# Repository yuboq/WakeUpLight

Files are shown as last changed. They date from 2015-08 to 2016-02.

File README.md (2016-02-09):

Currently, this device turns on LED strip at 5AM, and gradually increases in brightness in a half hour period.
Demo can be found here:
https://youtu.be/3JCAbMRWAIY

Eventually, the goal for this project is to create a beautiful standalone alarm clock that can help others wake up more naturally, similar to the Philips Wake Up Light, but with more customizations

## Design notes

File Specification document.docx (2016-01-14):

# Arduino wakeup light documentation

By Yubo Qiu

August 9, 2015

This functional specification will be available in PDF format for those who don’t have/use Word.

# Change Log

Author | Date | Notes
Yubo Qiu | Aug 9, 2015 | Initial Draft

Table of Contents

# 1. Introduction

## 1.1 Brief History of this project

This project started because my mother said that she was always waking up tired in the winter. After some research, I figured out that she was tired because the alarm clock would jolt her awake, instead of being woken up by the sunrise, like in summer. A quick search suggested that the Philips wake-up light would be a great solution to this, but costed $100 or so. I wanted a cheaper solution, so I decided to go the DIY route. I figured that since I already had some background in PCB development, this would be a great opportunity to go from initial concept to final delivery. I can also learn a bit about microcontrollers along the way!

Of course, the first thing was to look online, but I quickly found that those DIY solutions were unpolished. Of course, my solution might end up the same, but at least I’ll have control over that and decide the tradeoffs on my own terms. So, I ended up deciding to build this entire project from scratch, just to know how it feels.

## 1.2 Purpose of this document

This document is intended to describe functional specifications of the wake-up light. This document specifies the all components of this project, including PCB, firmware, mechanical and debugging. The intended audience is for anyone looking for a practical beginner project, and for developers to make sure that all design criteria are met.

## 1.3 Scope of the project

The wakeup light gradually increases the brightness of the LED strips to simulate a sunrise. This provides a more natural wake-up, rather than an alarm clock to jolt you awake. This project is also intended to be a starting point for anyone else wanting to build a wake-up light themselves—it doesn’t require advanced knowledge of circuit design or programming, instead, it requires you to follow through.

# 2. General Description

The wakeup light gradually increases the brightness of the LED strips to simulate a sunrise. Since all the code is on Github, I encourage the end user to change the code to make the light better.

## 2.1 Functions

## 2.2 Cost

The cost is at around $30 for hardware alone, however, depending on where you source components, you may get it cheaper. You do not need quality components, stuff from eBay is fine (that’s where I sourced my stuff).

# 3. Functional Requirements

## 3.1 User Interface

The rotary encoder controls the majority of the configurations, where turning the encoder scrolls through the menu items, and pushing the button selects the item. such as alarm/clock/date set, alarm on/off, and light on/off. When the alarm is set, the Arduino gradually turns up an LED strip over a specified period (default 30min). Another functions include a delayed off, where you gradually dim the light before turning off.

## 3.2 Software

Stuff happens here

### 3.2.1 State machine for rotary encoder

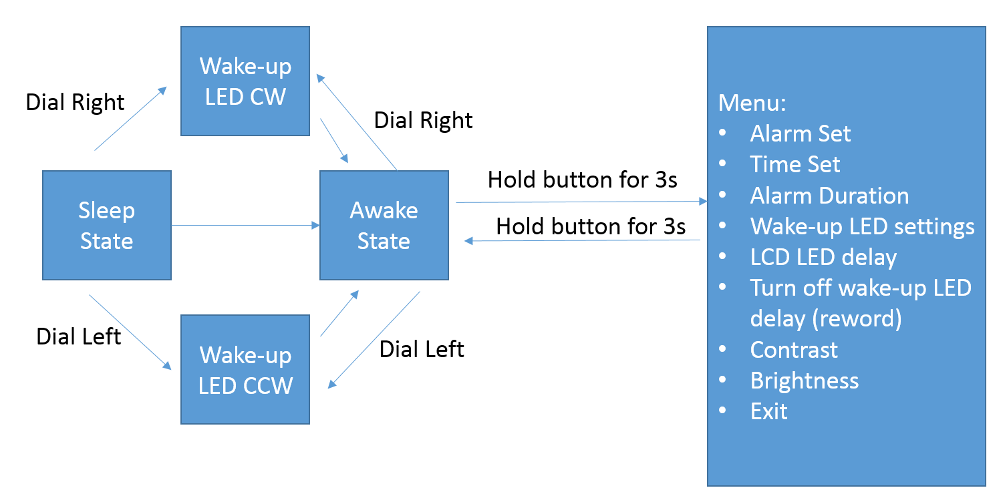
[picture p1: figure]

#### 3.2.1.1 Sleep State

By default the clock is in sleep state, where the LCD LED is off, and the clock and date is shown

#### 3.2.1.2 Awake State

When the dial is turned left/right or pressed, then the clock will enter awake state where the LCD LED will turn on.

#### 3.2.1.3 Menu state

The menu state will be displayed when the button is held for 3s. TO leave the menu state, hold the button for 3s, or navigate to exit.

### 3.2.2 Wi-Fi

Add wi-fi compatability to control from web-browser

### 3.2.3 Mobile app

Android or iOS app that connects to the device through wifi

  3.3 Block diagram

## 3.4 Hardware

- 16x2 LCD with backlight
- Custom PCB
- Arduino nano or mini
- External Clock oscillator
- Push button
- Caps and resistors
- LED light strip

# 4. Mechanical

- All components must fit in a LxWxH: 3.5” x 3.5” x 1.5” enclosure
- Rotary encoder will protrude from the middle of the enclosure

# 5. Debugging

# 6. Further development

Wi-fi integration for android/iOS

Remote control functionality

Add a python wrapper

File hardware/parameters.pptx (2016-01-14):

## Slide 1

Block Diagram

12V supply

Push Button (rotary encoder)

Arduino Mini/Nano

FETs

LED strip

External clock

Fog ligts

Serial Comm

16x2 LCD display

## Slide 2

(Rough) Layout*

PCB Specifications:
- 2” x 2”
- 2 layer board
- 1.6mm thick
- HASL finish
- 1 oz copper
- Min trace 6mil (recommend >8mil)
- Min space 6min (recommended >8mil)
- Finished hole (0.3mm – 6.3mm)

Enclosure Specifications:
- L x W x H: 3.5” x 3.5” x 1.5”
- Rotary encoder button must protrude from the middle of the enclosure

3.5”

2”

Arduino mini/nano dual footprint

LCD display

Power stuff

Serial header

FETs

External clock

LED header

2”

Btn

3.5”

*Not to scale

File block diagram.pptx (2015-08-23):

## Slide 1

Wake-up LED CW

Menu:
- Alarm Set
- Time Set
- Alarm Duration
- Wake-up LED settings
- LCD LED delay
- Turn off wake-up LED delay (reword)
- Contrast
- Brightness
- Exit

Dial Right

Sleep State

Dial Left

Dial Right

Awake State

Dial Left

Hold button for 3s

Hold button for 3s

Wake-up LED CCW

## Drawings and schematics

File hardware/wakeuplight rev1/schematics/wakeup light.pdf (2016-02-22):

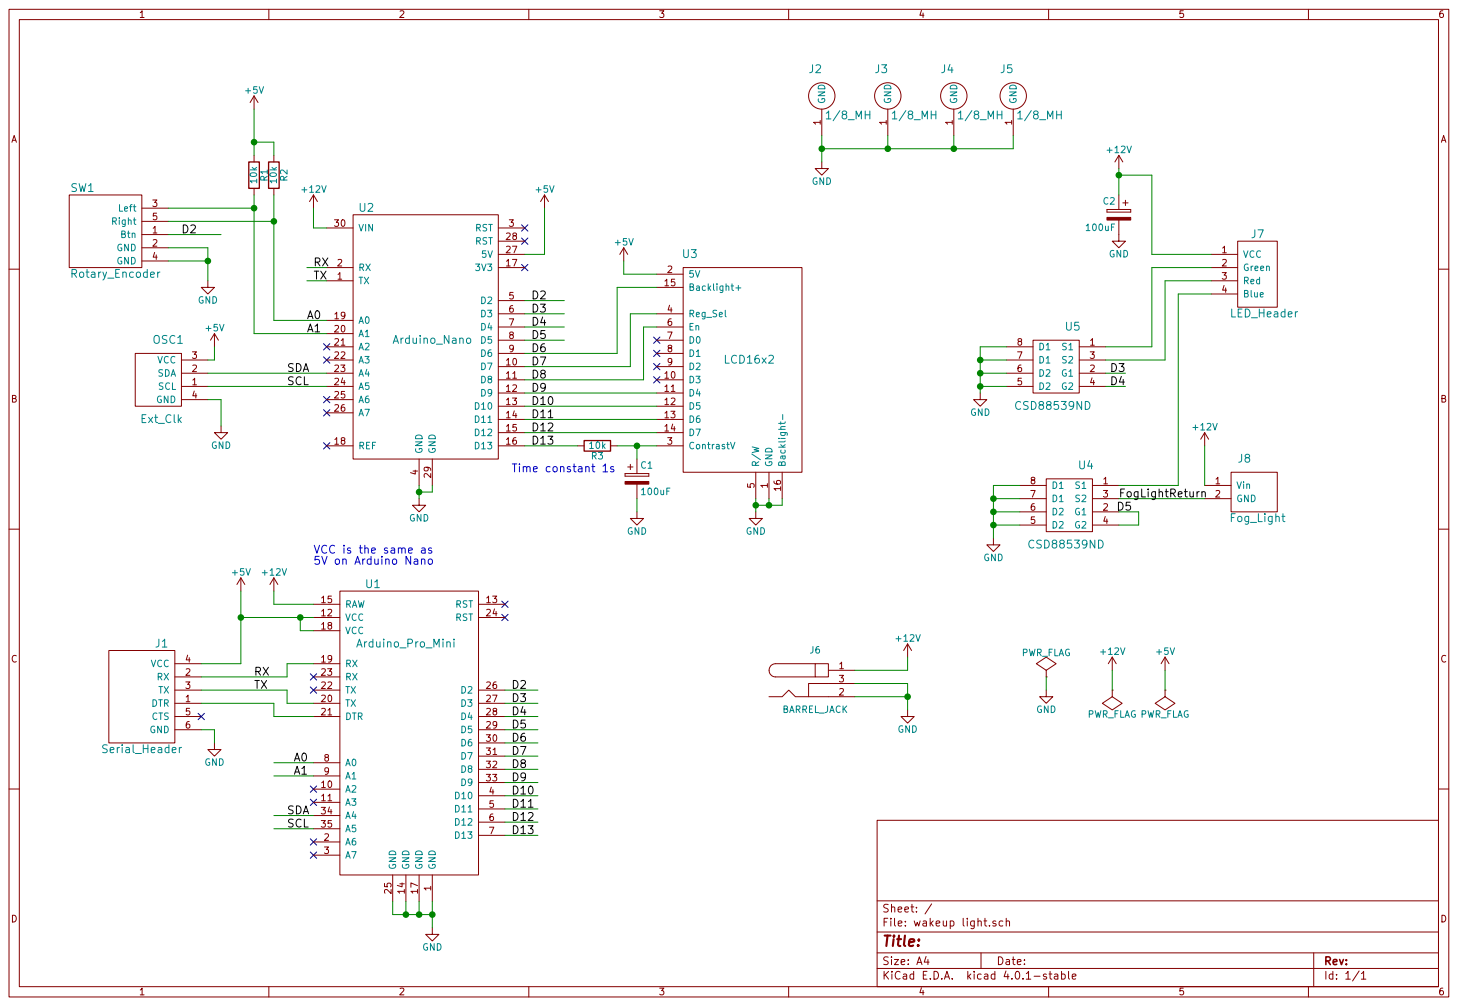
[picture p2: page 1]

+12V GND
A1A0 SCL
VCC is the same as 5V on Arduino Nano GNDGND

1 A6 2 A7 3 D10 4 D11 5 D12 6 D13 7 A0 8 A1 9 A2 10 TX 20 D6 30 A3 11 DTR 21 D7 31 VCC 12 TX 22 D8 32 RST 13 RX 23 D9 33 GND 14 RST 24 A4 34 RAW 15 GND 25 A5 35 D2 26 GND 17 D3 27 VCC 18 D4 28 RX 19 D5 29 U1 Arduino_Pro_Mini VCC 1 Green 2 Red 3 Blue 4 J7

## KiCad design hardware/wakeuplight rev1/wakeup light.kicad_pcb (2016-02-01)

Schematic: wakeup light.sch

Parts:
C1, C2: CP; Cap_Fat_1000uF_25V
J1: Serial_Header; Pin_Header_Straight_1x06
J2, J3, J4, J5: 1/8_MH; 2.5mm_MH
J6: BARREL_JACK
J7: LED_Header; Pin_Header_Straight_1x04
J8: Fog_Light
OSC1: Ext_Clk; External_Clock
R1, R2, R3: R; R_0603_HandSoldering
SW1: Rotary_Encoder; Push_Button
U1: Arduino_Pro_Mini
U2: Arduino_Nano
U3: LCD16x2; LCD_16x2
U4, U5: CSD88539ND; SOIC-8-N

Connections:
+5V: J1.4 (VCC), OSC1.3 (VCC), R1.1, R2.1, U1.12 (VCC), U1.18 (VCC), U2.27 (5V), U3.2 (5V)
+12V: C2.1, J6.1, J7.1 (VCC), J8.1 (Vin), U1.15 (RAW), U2.30 (VIN)
/A0: R2.2, SW1.5 (Right), U1.8 (A0), U2.19 (A0)
/A1: R1.2, SW1.3 (Left), U1.9 (A1), U2.20 (A1)
/D2: SW1.1 (Btn), U1.26 (D2), U2.5 (D2)
/D3: U1.27 (D3), U2.6 (D3), U5.2 (G1)
/D4: U1.28 (D4), U2.7 (D4), U5.4 (G2)
/D5: U1.29 (D5), U2.8 (D5), U4.2 (G1), U4.4 (G2)
/D6: U1.30 (D6), U2.9 (D6), U3.15 (Backlight+)
/D7: U1.31 (D7), U2.10 (D7), U3.4 (Reg_Sel)
/D8: U1.32 (D8), U2.11 (D8), U3.6 (En)
/D9: U1.33 (D9), U2.12 (D9), U3.11 (D4)
/D10: U1.4 (D10), U2.13 (D10), U3.12 (D5)
/D11: U1.5 (D11), U2.14 (D11), U3.13 (D6)
/D12: U1.6 (D12), U2.15 (D12), U3.14 (D7)
/D13: R3.2, U1.7 (D13), U2.16 (D13)
/FogLightReturn: J8.2 (GND), U4.3 (S2)
/RX: J1.2 (RX), U1.19 (RX), U2.2 (RX)
/SCL: OSC1.1 (SCL), U1.35 (A5), U2.24 (A5)
/SDA: OSC1.2 (SDA), U1.34 (A4), U2.23 (A4)
/TX: J1.3 (TX), U1.20 (TX), U2.1 (TX)
GND: C1.2, C2.2, J1.6 (GND), J2.1, J3.1, J4.1, J5.1, J6.2, J6.3, OSC1.4 (GND), SW1.2 (GND), SW1.4 (GND), U1.1 (GND), U1.14 (GND), U1.17 (GND), U1.25 (GND), U2.4 (GND), U2.29 (GND), U3.1 (GND), U3.5 (R/W), U3.16 (Backlight-), U4.5 (D2), U4.6 (D2), U4.7 (D1), U4.8 (D1), U5.5 (D2), U5.6 (D2), U5.7 (D1), U5.8 (D1)
unnamed: C1.1, R3.1, U3.3 (ContrastV)
unnamed: J1.1 (DTR), U1.21 (DTR)
unnamed: J7.2 (Green), U5.1 (S1)
unnamed: J7.3 (Red), U5.3 (S2)
unnamed: J7.4 (Blue), U4.1 (S1)

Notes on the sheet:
VCC is the same as 5V on Arduino Nano

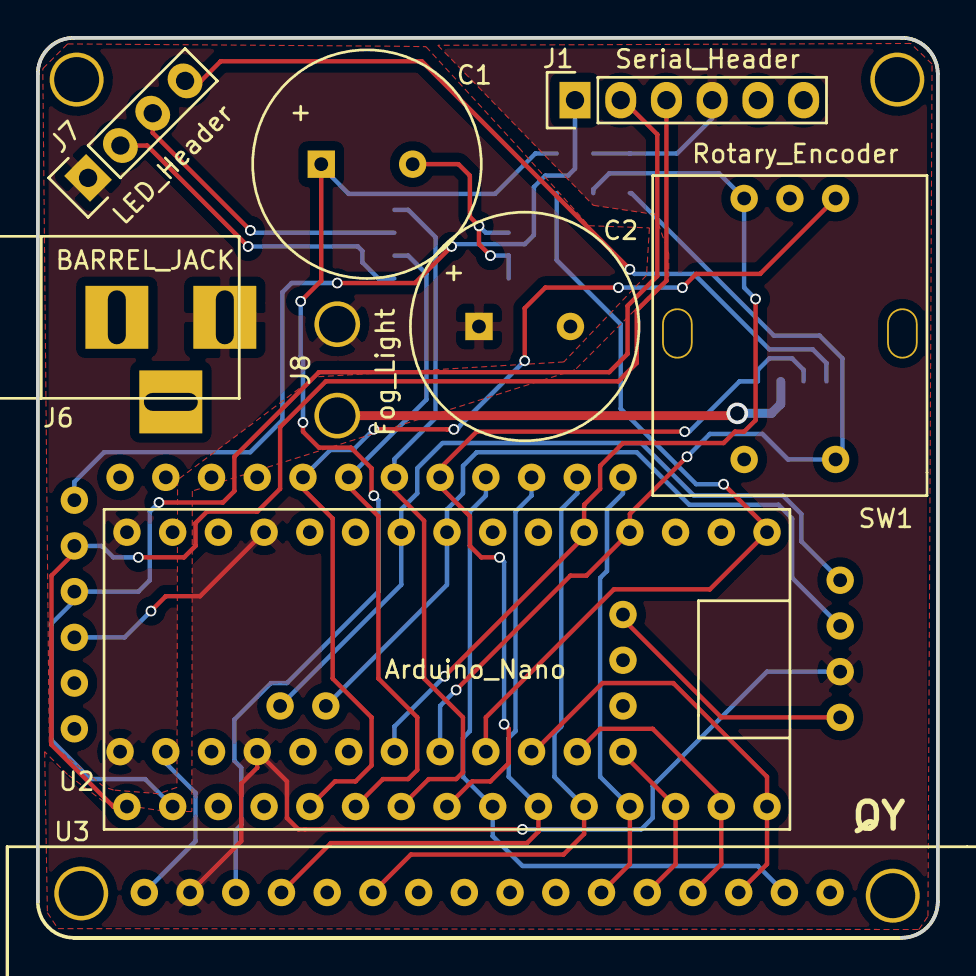
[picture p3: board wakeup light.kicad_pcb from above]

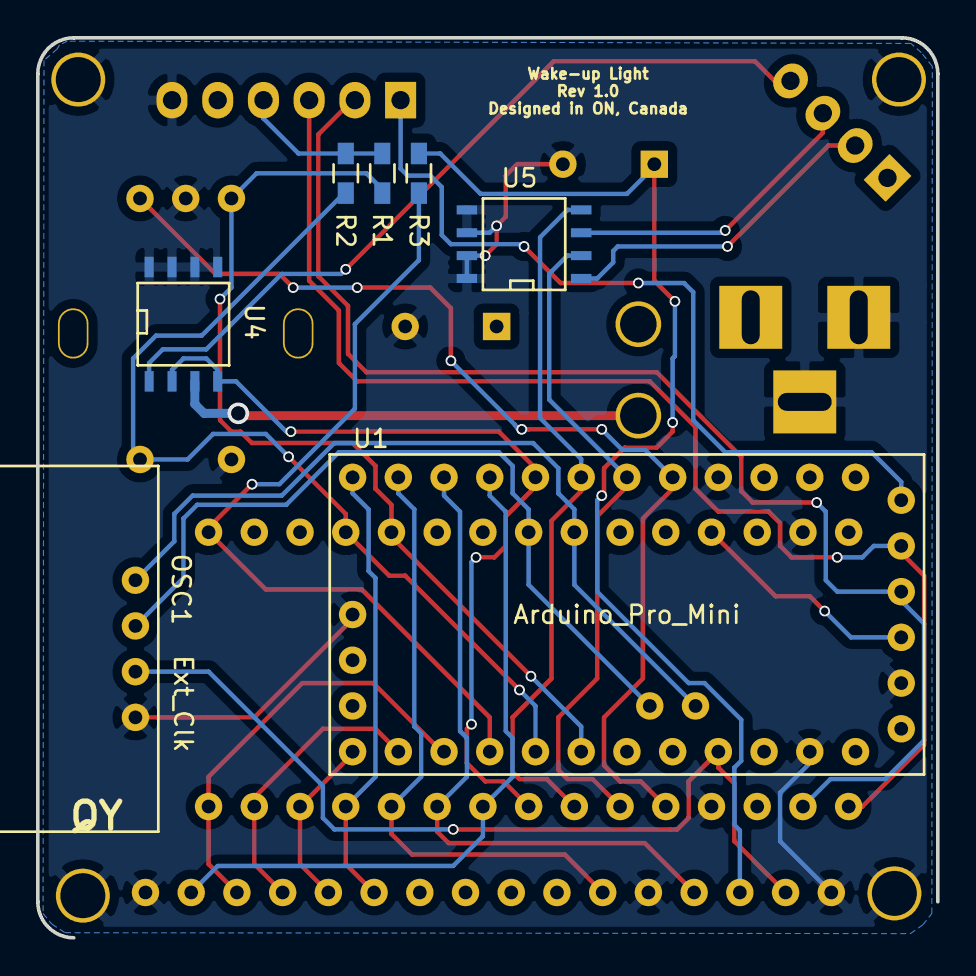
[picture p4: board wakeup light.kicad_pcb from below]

Board: 2 copper layers, 50.0 x 50.0 mm, 20 parts (7 on the bottom side), 27 nets.

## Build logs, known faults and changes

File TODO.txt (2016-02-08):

-----------High priority------------
Reorganize all folders in a more readable format
clean up and modulize the different functions in wakelight.ino
Add a rotary encoder switch to trigger "snooze" or "alarm off"
Use button on rotary encoder to trigger a "menu" for setting up time/alarm without computer input
	Initially, I wanted to use the left and right switches as interrupts using the A0 and A1 pins. After some testing, it turns out that the (cheap ebay) rotary encoder bounces too much. In stead, I'm stuck with having to include a pull-up and reading the A0 and A1, and using software to debounce it. In hindsight, I couldn't have used hardware to debounce it anyways, b/c my through-hole capacitors are too big, and I don't own any surface mount caps. 

------------Low priority--------------

implement a python wrapper for menu
bluetooth with phone
source brighter LED's

------------------COMPLETED--------------
Boards Ordered! (Jan 31, 2016)
major components placed, need to wire them up (Jan31, 2016)
round off edges of the board, Need mounting holes (Jan 31, 2016)
Add mounting holes to schematics (Jan 31, 2016)
Schematics double checked with DRC and annotated (Jan 27, 2016)
Completed the following footprints: Arduion Nano, Arduino Mini, External Clock, Fog Light, LCD 16x2, push button, caps (Jan 25, 2016)
Wiring schematics is complete (Jan 23, 2016)
Make custom symbols for: FETS, foglights, pushbutton (completed Jan 20, 2016)
Make arduino symbols look nicer (i.e. group GPIO pins, power pins, gnd, etc) (completed Jan 20, 2016)
add external I2C oscillator function (October 15, 2015)
Add pullup resistor to left and right knobs for rotary encoder and connect to ADC. This clears up the other 2 GPIOs for full control of tri-color LED strips. Have the btn remain as a GPIO interrupt (Oct 23, 2016)

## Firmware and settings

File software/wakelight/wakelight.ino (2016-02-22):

#include <TimeLib.h>
#include <LiquidCrystal.h>
#include <Time.h>
#include <Wire.h>
#define DS3231_I2C_ADDRESS 0x68
/*
 * This program is a wake-up light.
 * TODO:
 * -Get clock and date working on the LCD screen
 * -Control the backlight using PWM 7
 * -Control the contrast using PWM, pin 6
 * -Control the LEDs using PWM using pins 9,10,11
 * that should be it.
 *
 * TODO:
 * create a settings menu (press and hold rotary encoder button)
 * Auto off backlight
 * birghtness control
 *
 */




//the state variable controls the current state, where:
//state=0 is sleep state
//state=1 is awake state
//state=2 is wake-up LED brightness increase
//state=3 is wake-up LED brightness decrease
//state=4 is menu. Menu will be used when I get python wrapper working :)
int state = 1;
LiquidCrystal lcd(12, 8, 4, 5, 6, 7);
int redPin = 9; //pin for red wakeup LED
int greenPin = 10; //pin for green wakeup LED
int bluePin = 11; //pin for blue wakeup LED
int contrastPin = 3; // pin for contrast PWM through a LPF, requires 0.81V
float brightness = 0;
int alarmSet[] = {14, 50};
int currentRed = 0; //current wake-up LED RED brightness
int currentGreen = 0; // current wake-up LED Green brightness
int currentBlue = 0; // current wake-up LED Blue brightness
int LCDLED = 13;//lcd LED pin
byte extHr, extMin, extSec, extWeekday, extDay, extMonth, extYr;

//button variables
bool buttonEvent, leftEvent, rightEvent;

long timeGrab;//used to store time alarm was tripped as reference

//setup flags: active high
bool ishourFormat12, isAlarm, clearLCD;
bool alarmFlag;
String minuteUpdate; //when the minute hand increases, change PWM of LEDs

//function calls goes here
String monthDay() {
  String date;
  date = (day() < 10) ? "0" + String (day()) : String (day());
  switch (month()) {
    case 1:
      return "Jan " + date;
      break;
    case 2:
      return "Feb" + date;
      break;
    case 3:
      return "Mar" + date;
      break;
    case 4:
      return "Apr" + date;
      break;
    case 5:
      return "May" + date;
      break;
    case 6:
      return "Jun" + date;
      break;
    case 7:
      return "Jul " + date;
      break;
    case 8:
      return "Aug" + date;
      break;
    case 9:
      return "Sep" + date;
      break;
    case 10:
      return "Oct" + date;
      break;
    case 11:
      return "Nov" + date;
      break;
    case 12:
      return "Dec" + date;
      break;
    default:
      return "MMM" + date;
  }
}

String weekDay() {
  switch (weekday()) {
    case 1:
      return "  Sun"; //the spaces are used for spacing
      break;
    case 2:
      return "  Mon";
      break;
    case 3:
      return " Tues";
      break;
    case 4:
      return "  Weds";
      break;
    case 5:
      return " Thur";
      break;
    case 6:
      return "  Fri";
      break;
    case 7:
      return "Sat";
      break;
    default:
      return "DDD";
      break;
  }
}



//turns down wakeup LEDs
void lightsDown() {
  analogWrite(redPin, 0);
  analogWrite(greenPin, 0);
  analogWrite(bluePin, 0);
}
//turn up wakeup LEDs
void lightsUp() {

}
//function call for alarm. Produces a brightness gradient from 0 to
//100% brightness over half an hour.
void alarmArmed() {
  //arms the alarm by grabbing the current now() and store it to memory
  if ((hour() == alarmSet[0]) && ((minute()) == alarmSet[1]) && (alarmFlag == 0)) {
    //will repeat gradually increasing brightness if interval is less than 1min
    alarmFlag = 1;
    timeGrab = now();//used to compare for the 30min of brightness increasing
    //Serial.println("current timeGrab is " + String(timeGrab));
  }
}
void alarm(long tripAlarmTime) {
  //ends alarm in 30 minutes from when timeGrab is set. dearms alarm if button is pushed
  //Serial.println("current tripAlarmTime is" + String(tripAlarmTime));
  //Serial.println("current now is " + String(now()));
  if (alarmFlag) {
    float alarmPeriod = 60.0;
    long endAlarm = tripAlarmTime + long(alarmPeriod);
    if (endAlarm >= now()) {
      brightness = (((alarmPeriod - (endAlarm - now())) / alarmPeriod) * 255);
      //Serial.println("the brightness now is " + String(brightness));
      analogWrite(9, (int) brightness);
      analogWrite(10, (int) brightness);
      analogWrite(11, (int) brightness);
    }
    else {
      alarmFlag = 0;
    }
  }
}

void printTime() {
  //prints the current time in 12hr or 24hr format
  String PMAM, minuteTime, hourTime;
  if (ishourFormat12) {
    PMAM = isPM() ? "PM" : "AM";
    minuteTime = (minute() < 10) ? "0" + String(minute()) : String(minute());
    hourTime = (hourFormat12() < 10) ? " " + String(hourFormat12()) : String(hourFormat12());
  }
  else {
    hourTime = (hour() < 10) ? "0" + String(hour()) : String(hour());
    minuteTime = (minute() < 10) ? "0" + String(minute()) : String(minute());
    PMAM = "";
  }
  lcd.setCursor(4, 0);
  lcd.print (hourTime + ":" + minuteTime + PMAM);
}

void printDate() {
  lcd.setCursor(0, 1);
  lcd.print (weekDay() + " " + monthDay());
}

void sleepState() {
  printTime();
  printDate();
  analogWrite(LCDLED, LOW);
}

void wakeLEDUp() {


}
void wakeLEDDown() {

}
void awakeState() {
  printTime();
  printDate();
  analogWrite(LCDLED, HIGH);
}

//bcdToDec used for reformating time received from DS3231
byte bcdToDec(byte val)
{
  return( (val/16*10) + (val%16) );
}

//read the external time
void readDS3231time(byte *extSec,
byte *extMin,
byte *extHr,
byte *extWeekday,
byte *extDay,
byte *extMonth,
byte *extYr)
{
  Wire.beginTransmission(DS3231_I2C_ADDRESS);
  Wire.write(0); // set DS3231 register pointer to 00h
  Wire.endTransmission();
  Wire.requestFrom(DS3231_I2C_ADDRESS, 7);
  // request seven bytes of data from DS3231 starting from register 00h
  *extSec = bcdToDec(Wire.read() & 0x7f);
  *extMin = bcdToDec(Wire.read());
  *extHr = bcdToDec(Wire.read() & 0x3f);
  *extWeekday = bcdToDec(Wire.read());
  *extDay = bcdToDec(Wire.read());
  *extMonth = bcdToDec(Wire.read());
  *extYr = bcdToDec(Wire.read());
}

void setup() {
  // put your setup code here, to run once:
  Wire.begin();
  // initialize serial communication
  Serial.begin(9600);
  
  readDS3231time(&extSec, &extMin, &extHr, &extWeekday, &extDay, &extMonth, &extYr);
  setTime(extHr, //external hour
  extMin, //ext Minute
  extSec, //external second
  extDay, //external day
  extMonth, //external Month
  (2000+extYr));
  
  lcd.clear();
  lcd.begin(16, 2);
  //set led and contrast pins to output
  pinMode (LCDLED, OUTPUT);
  pinMode (redPin, OUTPUT);
  pinMode (bluePin, OUTPUT);
  pinMode (greenPin, OUTPUT);
  ishourFormat12 = 1;
  clearLCD = 1;
  analogWrite(contrastPin, 20);
  //alarm variables
  alarmFlag = 0;
}

void loop() {
  // put your main code here, to run repeatedly:
  // correct the text so that single digits dispaly as 0+digit

  alarmArmed();//check if alarm is armed
  alarm(timeGrab); //The period (in seconds) for increasing brightness

  
  switch (state) {
    case 0:
      sleepState();
      break;
    case 1:
      awakeState();
      break;
    case 2:
      wakeLEDUp();
      break;
    case 3:
      wakeLEDDown();
      break;
    default:
      sleepState();
  }
  delay(500);
}

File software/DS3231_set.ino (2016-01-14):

#include "Wire.h"
#define DS3231_I2C_ADDRESS 0x68
//convert normal decimal numbers to binary coded decimal
byte decToBcd(byte val)
{
  return( ( val/10*16) + (val%10));
}
// Convert binary coded decimal to normal decimal numbers
byte bcdToDec(byte val)
{
  return( (val/16*10) + (val%16) );
}
void setup() {
  // put your setup code here, to run once:
  Wire.begin();
  Serial.begin(9600);
  //set the initial time here
  //DS3231 seconds, minutes, hours, day, date, month, year
  //setDS3231time(0,22,15,02, 28,9,15);
}

void setDS3231time(byte second, byte minute, byte hour, byte dayOfWeek, byte dayOfMonth, byte month, byte year){
  //set time and data for DS3231
  Wire.beginTransmission(DS3231_I2C_ADDRESS);
  Wire.write(0);//set next input to start at the seconds register
  Wire.write(decToBcd(second)); //set seconds
  Wire.write(decToBcd(minute)); //set minutes
  Wire.write(decToBcd(hour)); //set hours
  Wire.write(decToBcd(dayOfWeek)); //set day of week(1=Sunday, 7= Saturday)
  Wire.write(decToBcd(dayOfMonth)); //set date ( 1 to 31)
  Wire.write(decToBcd(month)); //set month
  Wire.write(decToBcd(year)); //set year
  Wire.endTransmission();
}

void readDS3231time(byte*second,
byte *minute,
byte *hour,
byte *dayOfWeek,
byte *dayOfMonth,
byte *month,
byte *year){
  Wire.beginTransmission(DS3231_I2C_ADDRESS);
  Wire.write(0); //set DS3231 register pointer to 00h
  Wire.endTransmission();
  Wire.requestFrom(DS3231_I2C_ADDRESS,7);
  //request seven bytes of data from DS3231 starting from register 00h
  *second = bcdToDec(Wire.read() & 0x7f);
  *minute=bcdToDec(Wire.read());
  *hour = bcdToDec(Wire.read() & 0x3f);
  *dayOfWeek = bcdToDec(Wire.read());
  *dayOfMonth = bcdToDec(Wire.read());
  *month = bcdToDec(Wire.read());
  *year = bcdToDec(Wire.read());
  
}

void displayTime()
{
  byte second, minute, hour, dayOfWeek, dayOfMonth, month, year;
  // retrieve data from DS3231
  readDS3231time(&second, &minute, &hour, &dayOfWeek, &dayOfMonth, &month,
  &year);
  // send it to the serial monitor
  Serial.print(hour, DEC);
  // convert the byte variable to a decimal number when displayed
  Serial.print(":");
  if (minute<10)
  {
    Serial.print("0");
  }
  Serial.print(minute, DEC);
  Serial.print(":");
  if (second<10)
  {
    Serial.print("0");
  }
  Serial.print(second, DEC);
  Serial.print(" ");
  Serial.print(dayOfMonth, DEC);
  Serial.print("/");
  Serial.print(month, DEC);
  Serial.print("/");
  Serial.print(year, DEC);
  Serial.print(" Day of week: ");
  switch(dayOfWeek){
  case 1:
    Serial.println("Sunday");
    break;
  case 2:
    Serial.println("Monday");
    break;
  case 3:
    Serial.println("Tuesday");
    break;
  case 4:
    Serial.println("Wednesday");
    break;
  case 5:
    Serial.println("Thursday");
    break;
  case 6:
    Serial.println("Friday");
    break;
  case 7:
    Serial.println("Saturday");
    break;
  }
}
void loop()
{
  displayTime(); // display the real-time clock data on the Serial Monitor,
  delay(1000); // every second
}

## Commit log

2015-09-29 broke the light, but communicating with DS3231
    [wakeuplight.ino]
2015-09-29 deleted 'wakeuplight.ino' becuase it was linking c files. Created a single .ino called wakelight to resolve problem. LOL so bad. TODO: modulize the functions in waklight. At least it's reading and tu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
    [wakelight.ino]
2015-10-16 changed wakeup time to 6:15am. commmented out serial print statements
2016-01-14 Updated spec documents and reorganized stuff
    Updated todo list
    reorganized specification document
    Reorganized folders for more logical placement
    [wakeup light.kicad_pcb, wakeup light.sch]
2016-01-18 Added custom symbols for wake-up light
    Added symbols for:
    arduino mini, arduino nano, external clock, serial header, LED header,
    16x2 LCD. Updated TODO list
2016-01-19 Added more custom symbols
    Added custom symbols for: FETs, Foglights, pushbutton
    cleaned up arduino symbols by grouping GPIO pins, power pins, gnd, etc
2016-01-21 Started schematics
    Completed wiring for 16x2 LCD with Arduino Mini
    Completed Arduino mini wiring
    Fixed up some symbols so pins are grouped more logically
2016-01-22 updated schematic with a few more wires
    connected a few more wires to components, modified the serial header to
    fit nicer in schematic
    [wakeup light.sch]
2016-01-23 Completed rough schematic
    Everything should be there.
    [wakeup light.sch]
2016-01-26 Added footprints for all parts
2016-01-28 DRC on schematic is complete
    Modified pins on symbols to appropriate electrical type (input, output,
    bidirectional, etc)
    Annotated schematics
    Resolved all DRC errors.
    [wakeup light.sch]
2016-01-29 updated netlist and linked components to footprints
    [wakeup light.sch]
2016-01-31 components placed
    Schematics updated with mounting holes
    components placed, need to wire them up
    [_saved_wakeup light.sch]
2016-01-31 Completed layout
    Wiring complete
    Need to double check and send off to manufacture.
    [_saved_wakeup light.sch, wakeup light.kicad_pcb, wakeup light.sch]
2016-02-01 Boards ordered!
    gerbers generated and are on the way.
    [wakeup light-B.Cu.gbl, wakeup light-B.Mask.gbs, wakeup light-B.Paste.gbp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]
2016-02-08 Tests rotary encoder functionality in sandbox
2016-02-22 includes PDF schematics
    For easier reading!
    includes component values
    [wakeup light.sch]
